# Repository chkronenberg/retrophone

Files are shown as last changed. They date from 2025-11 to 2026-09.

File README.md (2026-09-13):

# ☎️ Retro Rotary SIP Phone  
**Convert a classic rotary dial phone into a working SIP VoIP phone using a Raspberry Pi Zero 2 W, Debian Trixie, Baresip and Python 3**







If you enjoyed this project or found it helpful in setting up your own retro phone, you can buy me a coffee to help keep the bells ringing and the code flowing. ☕👇  


---

## 📚 Table of Contents

- [Overview](#-overview)
- [Features](#-features)
- [Hardware Setup](#-hardware-setup)
- [Software Installation](#️-software-installation)
- [Web Interface](#️-web-interface)
- [Log Files & Helper Tools](#-log-files--helper-tools)
- [WLAN & Network Stability](#-wlan--network-stability)
- [Troubleshooting (Audio & SIP)](#-audio-troubleshooting)
- [Credits & References](#-credits--references)

---

## 🧭 Overview
This open-source project demonstrates how to interface **classic telephony hardware** — rotary dial, hook switch, and mechanical bells — with **modern VoIP systems**.  
Built on **Raspberry Pi Zero 2 W** running **Debian Trixie**, **Baresip**, and **Python 3**.

- 📞 Incoming / outgoing VoIP calls via Baresip  
- 🔔 Authentic mechanical ringing driven by GPIO  
- ⚙️ Pulse-dial decoding and SIP dialing  
- 🧠 Flask-based web interface for SIP, logs & services  
- 🔊 Dial-tone playback and full audio through USB headset  

> 💬 **Need help or want to learn more about this project?**  
> You can ask questions, get setup guidance or troubleshooting tips directly via the  
> [**RetroPhone Custom GPT Assistant**](https://chatgpt.com/g/g-691247a8e5c0819190373fa77746ca60-retrophone).

---

## 🧩 Features

| Function | Description |
|---|---|
| ✅ Incoming calls | Mechanical bells ring; lifting handset answers |
| ✅ Outgoing calls | Rotary pulses decoded & sent to SIP |
| ✅ Dial tone | Analog-like dial tone playback |
| ✅ Web UI | Manage SIP, logs & restart services |
| ✅ GPIO monitoring | Check hook / dial / return contacts |
| ✅ Systemd services | Autostart & self-recovery |
| ✅ Persistent call history | Last 20 calls retained across reboots |
| ✅ Central JSON configuration | SIP, GPIO, audio, logging and timing settings |
| ✅ Backup from Web UI | Progress display and disaster-recovery archive |

---

## 🪛 Hardware Setup

This project uses an authentic rotary dial telephone combined with modern Raspberry Pi hardware.  
Below is the list of components used and verified to work with the current design.

### 🧩 Origin Story

The rotary phone used in this build wasn’t bought online — it was discovered in the **grandfather’s attic**, covered in dust but still mechanically perfect.  
After some careful cleaning and rewiring, the phone found a new life as a fully working SIP client.

### ⚙️ Required Components

| Component | Description | Link to buy
|---|---|---|
| ☎️ Old-style rotary telephone | The prototype uses a PTT **Modell 29**, found in the family attic. Any similar pulse-dial model will work. | 
| 🥧 Raspberry Pi Zero 2W | Compact, low-power computer controlling GPIO and running the SIP stack. Any variant of the Zero 2 W will do. | [digitec.ch](https://www.digitec.ch/de/s1/product/raspberry-pi-zero-2-w-entwicklungsboard-kit-47938039)
| 🥧 16GB SD-Card | Cheap option to save the data and run the OS of our Retrophone. | [digitec.ch](https://www.digitec.ch/de/s1/product/silicon-power-microsdhc-s-uhs-i-16-gb-microsdhc-u1-uhs-i-speicherkarte-13911929)
| 🔌 2x Dual D4184 MOSFET module | Used as high-current switches to drive the twin mechanical bell coils directly from the Pi GPIO pins. | [AliExpress](https://de.aliexpress.com/item/1005006478302624.html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)
| ⚡ 2 × 1N4007 diodes (1A / 1000V) | Wired in reverse across the bell coil outputs from the D4184 MOSFETs. These protect the switches from the voltage spike generated when the magnetic field in the coils collapses. **Ensure the band faces the positive line!** | [AliExpress](https://de.aliexpress.com/item/1005009923993443.html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)
| 🔋 Power supply 12V → 35V | Boost converter used to power the mechanical bell coils. | [AliExpress](https://de.aliexpress.com/item/1005007187154351.html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)
| 🔋 Power supply 12V → 5V | Step-down converter used to power the Raspberry Pi. | [AliExpress](https://de.aliexpress.com/item/1005006365697021.html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)
| 🔌 12 V DC power adapter | Common supply feeding both converters above. | [AliExpress](https://de.aliexpress.com/item/1005006865934857.html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)
| 🔌 Plug Jack Connector 5.5*2.1mm | DC plug connector and panel mount DC socket. | [AliExpress](https://de.aliexpress.com/item/1005003371403398.html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)
| 🧠 Raspberry Pi GPIO breakout board | For clean wiring and to mount all discrete components safely. | [AliExpress](https://de.aliexpress.com/item/1005008700849079.html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)
| 🎧 USB audio adapter or old USB Headset | Provides microphone and speaker ports for handset audio. | [AliExpress](https://de.aliexpress.com/item/1005003697317297.html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)
| 🎧 Speaker and microphone | Provides microphone and speaker ports for handset audio. | [Speaker - AliExpress](https://de.aliexpress.com/item/1005001740737952.html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), [Microphone - AliExpress](https://de.aliexpress.com/item/1005008016850118.html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)
| 🔗 Micro-USB “On-The-Go” (OTG) cable | Connects the USB audio interface to the Raspberry Pi Zero 2 W. | [AliExpress](https://de.aliexpress.com/item/32828564442.html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)

> The D4184 MOSFET module drives the two bell coils (RING_A and RING_B).  
> Each coil is protected by a 1N4007 diode, preventing reverse voltage damage when the magnetic field collapses.  
> A single 12 V power source feeds both the bell (via boost converter) and the Raspberry Pi (via step-down converter).

### 🖨️ 3D-Printed Holder
To securely mount all components inside the old telephone, a custom 3D-printed holder is used.
Required part:  
👉 [3D-Printed Component Holder](media/holder.stl)

The holder is designed to fit perfectly into the telephone housing and can be mounted using the original screw holes. All electronic components are fixed directly onto the holder, keeping everything clean, stable, and reversible without modifying the original phone.

---

### 📈 Architecture & Wiring Diagram

Below is the complete wiring layout for the Retro Rotary SIP Phone hardware setup.  
It shows the Raspberry Pi Zero 2 W GPIO connections, MOSFET bell driver, diodes, and power converters.

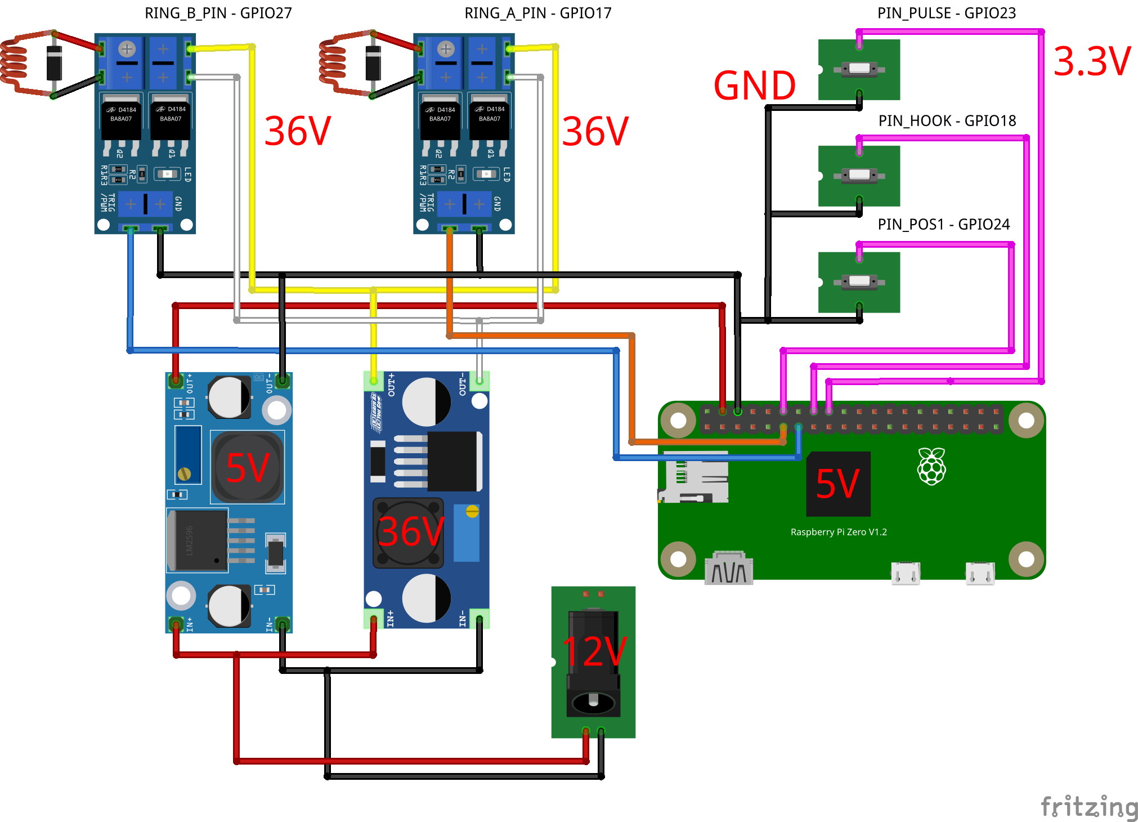
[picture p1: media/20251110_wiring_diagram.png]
Retro Rotary Phone Wiring Diagram


> **Tip:** Open the image in full size to see all GPIO labels and wiring colors clearly.  
> **Ensure you double-check the polarity of the 1N4007 diodes and the MOSFET inputs before powering on.**

```
+--------------------------------------------------------------+
|                     Retro Rotary SIP Phone                   |
|--------------------------------------------------------------|
|  Rotary Dial  |  Hook Switch  |  Bell Coils  |  USB Audio    |
|--------------------------------------------------------------|
|    GPIO 23    |    GPIO 18    |  GPIO 17/27  | Logitech H340 |
|               |               |              |    Headset    |
|--------------------------------------------------------------|
|  phone_daemon.py (Pulse/Hooks)  -> baresip (SIP stack)       |
|  ring_control.py (Bells)         -> GPIO Driver              |
|  webapp.py (Flask UI)            -> SIP + Logs + Control     |
+--------------------------------------------------------------+
```

---

### 🔩 GPIO Mapping Summary

| Signal | GPIO (BCM) | Description | Logic |
|---|---|---|---|
| HOOK | 18 | Handset switch | 0 = off-hook  1 = on-hook |
| PULSE | 23 | Rotary dial pulses | 1 = pulse active |
| POS1 | 24 | Dial return contact | 0 = dial turning |
| RING_A | 17 | Bell coil A | controlled by `ring_control.py` |
| RING_B | 27 | Bell coil B | controlled by `ring_control.py` |

> The original Swiss pulse-dial logic pulls to GND — no external pull-down resistors needed.
> All GPIO assignments can be changed later under **Settings** in the Web UI.

---

## ⚙️ Software Installation

### ⚙️ Automated Installation Script

To simplify setup, you can install and configure the entire RetroPhone environment with a single command using the `install_retrophone.sh` script.  
This script performs all required steps automatically:

- Installs system dependencies (Python, Flask, baresip, ALSA, etc.)  
- Creates required directories under `/usr/local/retrophone`, `/etc/retrophone`, and `/var/log/retrophone`  
- Copies all Python scripts and configuration files  
- Generates a default dial tone file  
- Sets correct permissions and sudo rules  
- Installs and enables the systemd services (`baresip`, `phone-daemon`, `retrophone-web`)  

**Run the following commands on your Raspberry Pi to use the script and install retrophone:**

```bash
cd /tmp
wget -O install_retrophone.sh https://raw.githubusercontent.com/chkronenberg/retrophone/main/install_retrophone.sh
chmod +x install_retrophone.sh
sudo ./install_retrophone.sh
```
>**🧠 Tip:**
>The script should be executed with **`sudo`** to ensure all directories, permissions, and services are created correctly.
>After completion, your Retro Rotary SIP Phone will be fully operational — including baresip registration, ringing, and web interface.

> **RetroPhone v2.0:** The automated installer is the recommended and authoritative installation method. The detailed steps below remain available as a reference for experienced users and custom installations.

### 1️⃣ Base System

Minimal Debian Trixie / Bookworm Lite.  
Enable SSH and network.

### 2️⃣ Dependencies

```bash
sudo apt-get update
sudo apt-get upgrade -y
sudo apt-get install -y python3 python3-flask python3-gpiozero python3-rpi.gpio \
  alsa-utils sox wget baresip
```

---

### 3️⃣ Create folders for **retrophone** and **baresip**

```bash
sudo mkdir -p /etc/retrophone/baresip
sudo mkdir -p /usr/local/retrophone
sudo mkdir -p /var/log/retrophone
sudo mkdir -p /run/retrophone
```

Run once to generate default config:

```bash
sudo -u pi baresip -f /etc/retrophone/baresip -e "quit"
```

### 4️⃣ Configure baresip

**Create the initial config-file for baresip**
Edit `/etc/retrophone/baresip/config`:

```bash
sudo tee /etc/retrophone/baresip/config >/dev/null <<'EOF'
#
# baresip configuration
#
#------------------------------------------------------------------------------

# Core
poll_method             epoll           # poll, select, epoll ..

# SIP
#sip_listen             0.0.0.0:5060
#sip_certificate        cert.pem
sip_cafile              /etc/ssl/certs/ca-certificates.crt
#sip_trans_def          udp
#sip_verify_server      yes

# Call
call_local_timeout      120
call_max_calls          4
call_hold_other_calls   yes

# Audio
#audio_path             /usr/share/baresip
audio_player            alsa,plughw:0,0
audio_source            alsa,plughw:0,0
audio_alert             alsa,null

#ausrc_srate            48000
#auplay_srate           48000
audio_srate             48000
#ausrc_channels         0
#auplay_channels        0
#audio_txmode           poll            # poll, thread
audio_level             no
ausrc_format            s16             # s16, float, ..
auplay_format           s16             # s16, float, ..
auenc_format            s16             # s16, float, ..
audec_format            s16             # s16, float, ..
audio_buffer            20-160          # ms

# AVT - Audio/Video Transport
rtp_tos                 184
#rtp_ports              10000-20000
#rtp_bandwidth          512-1024 # [kbit/s]
rtcp_mux                no
jitter_buffer_type      fixed           # off, fixed, adaptive
jitter_buffer_delay     5-10            # frames
#jitter_buffer_wish     6               # frames for start
rtp_stats               no

#------------------------------------------------------------------------------
# Modules

# UI Modules
module                  stdio.so
module                  httpd.so

# Audio driver Modules
module                  alsa.so

# Media NAT modules
module                  stun.so
module                  turn.so
module                  ice.so

#------------------------------------------------------------------------------
# Temporary Modules (loaded then unloaded)

module_tmp              uuid.so
module_tmp              account.so

#------------------------------------------------------------------------------
# Application Modules

module_app              auloop.so
module_app              contact.so
module_app              debug_cmd.so
module_app              menu.so
module_app              ctrl_tcp.so
module_app              vidloop.so

#------------------------------------------------------------------------------
# Module parameters

# UI Modules parameters
cons_listen             0.0.0.0:5555 # cons - Console UI UDP/TCP sockets

http_listen             127.0.0.1:8000 # httpd - HTTP Server

ctrl_tcp_listen         0.0.0.0:4444 # ctrl_tcp - TCP interface JSON

evdev_device            /dev/input/event0

# Opus codec parameters
opus_bitrate            28000 # 6000-510000

vumeter_stderr          yes

# Selfview
video_selfview          window # {window,pip}

# Menu
ring_aufile             none
EOF
```

**Create config file for the useraccount**
Edit `/etc/retrophone/baresip/accounts`:

```bash
sudo tee /etc/retrophone/baresip/accounts >/dev/null <<'EOF'
; YOUR ACCOUNT
<sip:phonenumber@sip.domain.url>;auth_user=USERNAME;auth_pass=YOUR_PASSWORD;outbound="sip:sip.domain.url;transport=udp";regint=300
EOF
```

---

### 5️⃣ Directory Structure

```bash
sudo mkdir -p /usr/local/retrophone /var/log/retrophone /run/retrophone
sudo mkdir -p /etc/retrophone
sudo chown -R pi:pi /usr/local/retrophone /var/log/retrophone /run/retrophone /etc/retrophone
sudo tee /etc/tmpfiles.d/retrophone.conf >/dev/null <<'EOF'
d /run/retrophone 0755 pi pi -
EOF
sudo systemd-tmpfiles --create /etc/tmpfiles.d/retrophone.conf
```

Copy all application files and install the shared configuration:

```bash
sudo cp files/gpio_monitor.py files/gpio_hook_monitor.py files/ring_control.py \
  files/phone_daemon.py files/webapp.py files/backup_retrophone.sh \
  files/persist_logs.sh files/favicon.ico /usr/local/retrophone/
sudo cp files/config.example.json /etc/retrophone/config.json
sudo chmod +x /usr/local/retrophone/*.py
sudo chmod +x /usr/local/retrophone/*.sh
sudo chown pi:pi /etc/retrophone/config.json
sudo chmod 640 /etc/retrophone/config.json
```

---

### 6️⃣ Create a Dial Tone

```bash
sox -n -r 8000 -c 1 /usr/local/retrophone/dialtone.wav synth 10 sin 425
```

---

### 7️⃣ Additional Permissions for "pi"

```bash
sudo visudo
```

Add:

```text
pi ALL=(ALL) NOPASSWD: /usr/bin/systemctl restart baresip.service
pi ALL=(ALL) NOPASSWD: /usr/bin/systemctl restart phone-daemon.service
pi ALL=(ALL) NOPASSWD: /usr/bin/systemctl restart retrophone-web.service
pi ALL=(root) NOPASSWD: /usr/local/retrophone/backup_retrophone.sh backup
```

**Permissions for the Web UI to change the SIP account**
```bash
sudo chown -R pi:pi /etc/retrophone/baresip
sudo chmod 640 /etc/retrophone/baresip/accounts
```

---

### 8️⃣ Systemd Services

#### 📞 `/etc/systemd/system/phone-daemon.service`

```bash
sudo tee /etc/systemd/system/phone-daemon.service >/dev/null <<'EOF'
[Unit]
Description=RetroPhone Dial/Hook Daemon
After=network.target sound.target baresip.service

[Service]
ExecStart=/usr/bin/python3 /usr/local/retrophone/phone_daemon.py
Restart=on-failure
User=pi
Group=pi
NoNewPrivileges=false

[Install]
WantedBy=multi-user.target
EOF

sudo systemctl daemon-reload
sudo systemctl enable --now phone-daemon.service

```

#### 🌐 `/etc/systemd/system/retrophone-web.service`
```bash
sudo tee /etc/systemd/system/retrophone-web.service >/dev/null <<'EOF'
[Unit]
Description=RetroPhone Web UI
After=network.target

[Service]
ExecStart=/usr/bin/python3 /usr/local/retrophone/webapp.py
WorkingDirectory=/usr/local/retrophone
User=pi
Group=pi
Environment=RETRO_WEB_USER=admin
Environment=RETRO_WEB_PASS=secret
Restart=on-failure
NoNewPrivileges=false

[Install]
WantedBy=multi-user.target
EOF

sudo systemctl daemon-reload
sudo systemctl enable --now retrophone-web.service

```

#### 📡 `/etc/systemd/system/baresip.service`
Edit `/etc/systemd/system/baresip.service`:

```bash
sudo tee /etc/systemd/system/baresip.service >/dev/null <<'EOF'
[Unit]
Description=baresip SIP client
After=network.target sound.target

[Service]
ExecStart=/usr/bin/baresip -f /etc/retrophone/baresip
Restart=on-failure
User=pi
NoNewPrivileges=false

[Install]
WantedBy=multi-user.target
EOF

sudo systemctl daemon-reload
sudo systemctl enable --now baresip.service

```

## 🖥️ Web Interface
Accessible at `http://<raspberrypi-ip>:8080`  

**Features**
- Configure the SIP account, GPIO pins, audio levels and expert timing values  
- Select the phone-daemon log level (`DEBUG`, `INFO`, `WARNING`, or `ERROR`)  
- View automatically refreshed phone, ring and baresip logs  
- View the persistent history of the last 20 calls, including missed calls  
- Create and monitor disaster-recovery backups  
- View temperature and WLAN status  
- Restart services and check their status (baresip / daemon / web)  

The shared configuration is stored in `/etc/retrophone/config.json`. Changes made in the Web UI are persistent; services that require the new values are restarted in a controlled manner.

Credentials are set via the `RETRO_WEB_USER` and `RETRO_WEB_PASS` environment variables in `retrophone-web.service`. The installer initially uses `admin` / `secret`; change these values before exposing the Web UI to an untrusted network.

<p align="center">
  <a href="media/webapp_login.png" target="_blank">
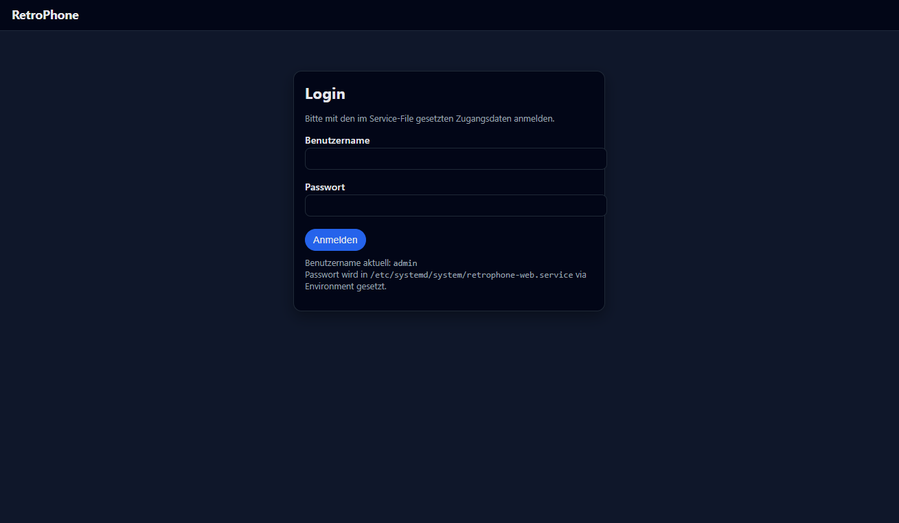
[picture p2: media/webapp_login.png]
Login View
    
  </a>
  <a href="media/webapp_dashboard_1.png" target="_blank">
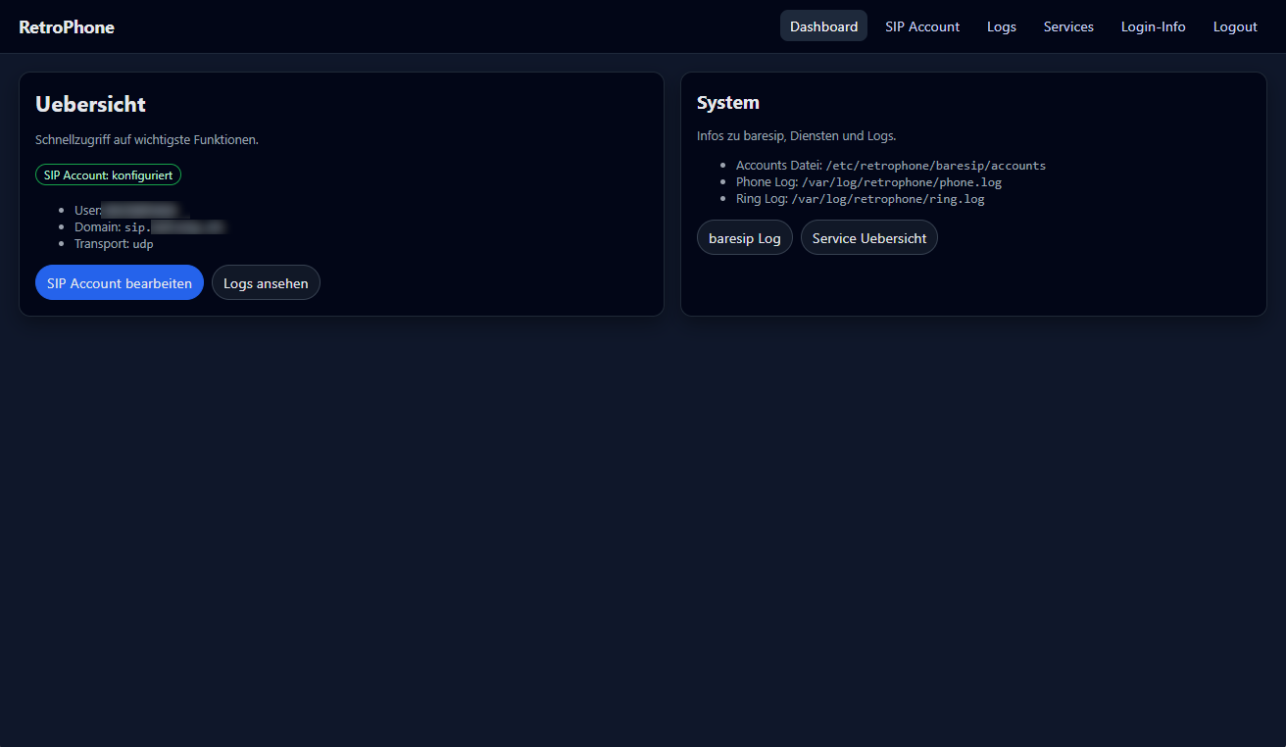
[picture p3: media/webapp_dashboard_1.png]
Dashboard View
    
  </a>
<a href="media/webapp_sip_account.png" target="_blank">
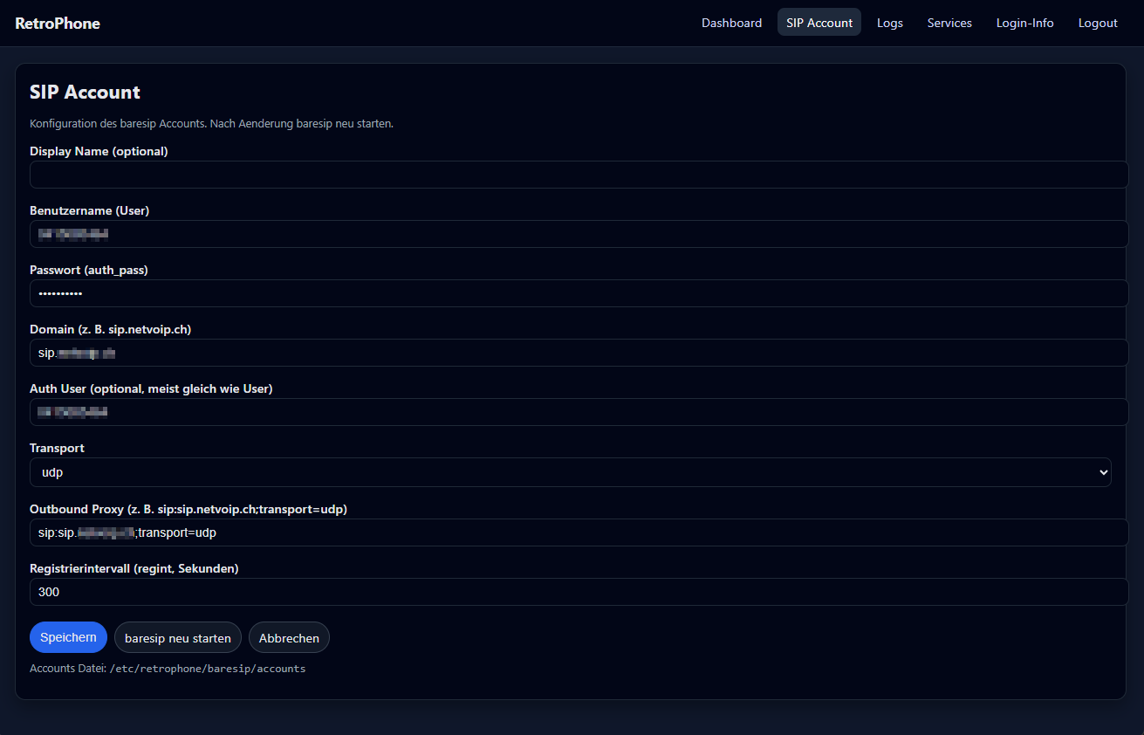
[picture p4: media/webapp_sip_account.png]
Dashboard SIP Account View
    
</a>
<a href="media/webapp_services.png" target="_blank">
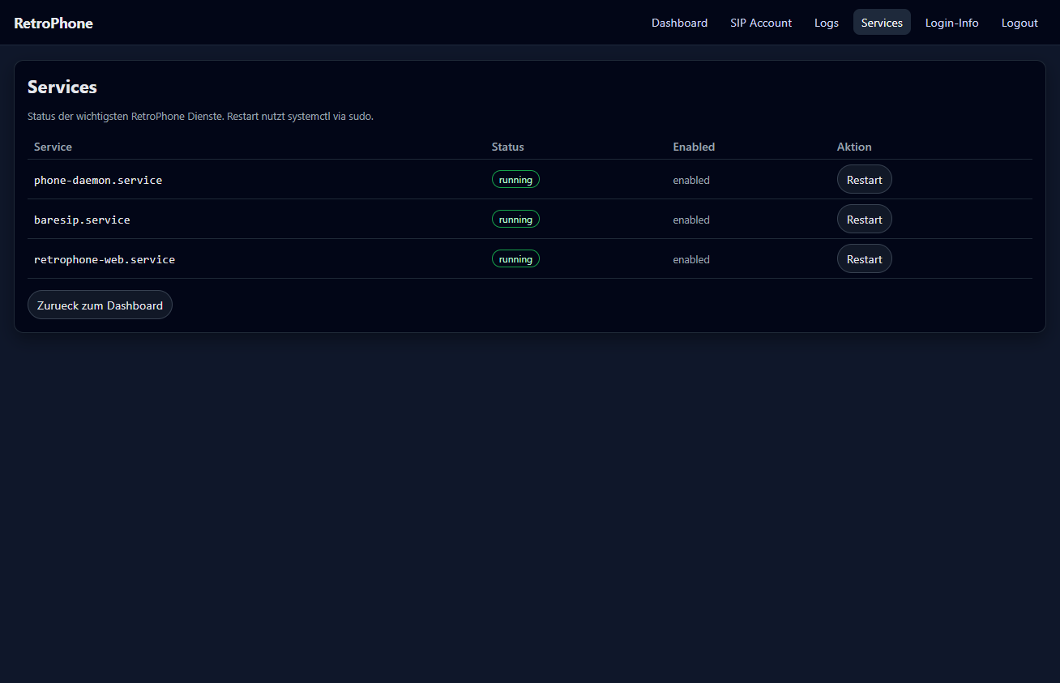
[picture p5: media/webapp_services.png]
Dashboard Services View
    
  </a>
</p>

<p align="center"><em>Click any image to view full size in a new tab.</em></p>

---

## 🧾 Log Files & Helper Tools

| Path | Description |
|---|---|
| `tail -f /run/retrophone/phone.log` | Main rotary daemon (dial, hook, call states) |
| `tail -f /run/retrophone/ring.log` | Bell control |
| `/var/log/retrophone/calls.jsonl` | Persistent call history restored after reboot |
| `journalctl -u baresip` | baresip SIP logs |

### 🆘 Helperscripts
| Script | Function |
|---|---|
| `gpio_monitor.py` | Show live GPIO states |
| `gpio_hook_monitor.py` | Hook only |
| `ring_control.py` | Manual ring test |

---

The technical phone and ring logs are intentionally stored below `/run/retrophone` and start fresh after a reboot. The call history is stored separately and persistently. Its location, along with all other paths, can be changed in `/etc/retrophone/config.json`.

---

## 📡 WLAN & Network Stability
The **Raspberry Pi Zero 2 W** uses the **Broadcom brcmfmac** Wi-Fi driver, which by default enables **power-saving**.  
During idle phases this can cause 🔻 lost SIP registrations, dropped Flask sessions, or temporary SSH timeouts.

The reference installation no longer uses NetworkManager. WLAN authentication is handled by **wpa_supplicant**, while addresses, routes and DNS are handled by **systemd-networkd** and **systemd-resolved**.

### 1️⃣ Replace NetworkManager with wpa_supplicant

> **Important:** Removing or stopping NetworkManager interrupts the current WLAN and SSH connection. Perform this migration from a local console or prepare all configuration files and enabled services before removing NetworkManager. Keep a backup of the previous network configuration.

Install the required components:

```bash
sudo apt-get update
sudo apt-get install -y wpasupplicant iw systemd-resolved
```

Generate the encrypted PSK with `wpa_passphrase`. The password is entered invisibly, is not stored in the shell history, and the clear-text comment normally produced by `wpa_passphrase` is removed:

```bash
read -rsp "WLAN password: " RETROPHONE_WIFI_PASSWORD; echo
wpa_passphrase "YOUR_SSID" "$RETROPHONE_WIFI_PASSWORD" \
  | sed '/^[[:space:]]*#psk=/d' \
  | sudo tee /etc/wpa_supplicant/wpa_supplicant.conf >/dev/null
unset RETROPHONE_WIFI_PASSWORD

sudo sed -i '1i ctrl_interface=DIR=/run/wpa_supplicant GROUP=netdev\nupdate_config=1\ncountry=CH\n' \
  /etc/wpa_supplicant/wpa_supplicant.conf
sudo sed -i '/^[[:space:]]*network={[[:space:]]*$/a\    scan_ssid=1' \
  /etc/wpa_supplicant/wpa_supplicant.conf
sudo chmod 600 /etc/wpa_supplicant/wpa_supplicant.conf
sudo ln -sfn /etc/wpa_supplicant/wpa_supplicant.conf \
  /etc/wpa_supplicant/wpa_supplicant-wlan0.conf
```

Replace `YOUR_SSID` with the actual WLAN name. The instance service `wpa_supplicant@wlan0` expects the interface-specific filename, so `wpa_supplicant-wlan0.conf` links to the central `wpa_supplicant.conf`. `scan_ssid=1` is required for the hidden WLAN used by the reference installation. Only the generated `network={...}` block is necessary when the Pi should not connect to any other WLAN.

Configure DHCP through `/etc/systemd/network/20-wlan0.network`:

```bash
sudo mkdir -p /etc/systemd/network
sudo tee /etc/systemd/network/20-wlan0.network >/dev/null <<'EOF'
[Match]
Name=wlan0

[Network]
DHCP=yes
EOF
```

Enable the replacement services before removing NetworkManager, then reboot:

```bash
sudo systemctl enable systemd-networkd.service
sudo systemctl enable systemd-resolved.service
sudo systemctl enable wpa_supplicant@wlan0.service
sudo ln -sf /run/systemd/resolve/stub-resolv.conf /etc/resolv.conf
sudo apt-get purge -y network-manager
sudo apt-get purge -y netplan.io cloud-init
sudo apt-get autoremove -y
sudo reboot
```

On the reference Raspberry Pi, APT also removed the dependent packages `rpi-usb-gadget`, `raspberrypi-net-mods`, and `rpi-cloud-init-mods`. Review APT's removal list before confirming because dependency packages can differ between Raspberry Pi OS releases and installations.

After reconnecting, verify the migration:

```bash
systemctl is-active systemd-networkd.service
systemctl is-active systemd-resolved.service
systemctl is-active wpa_supplicant@wlan0.service
networkctl status wlan0
```

All three services should report `active`, and `networkctl` should show `wlan0` as `routable`. The reference Pi currently receives its address by DHCP; a fixed address can instead be reserved for its MAC address on the router.

### 2️⃣ Temporarily disable Power Save
```bash
sudo iw dev wlan0 set power_save off
```

### 3️⃣ Disable Power Save permanently

Create a small systemd service so power saving is disabled after the WLAN interface is available:

```bash
sudo tee /etc/systemd/system/wlan-powersave-off.service >/dev/null <<'EOF'
[Unit]
Description=Disable WLAN power saving
After=sys-subsystem-net-devices-wlan0.device
Wants=sys-subsystem-net-devices-wlan0.device

[Service]
Type=oneshot
ExecStart=/usr/sbin/iw dev wlan0 set power_save off
RemainAfterExit=yes

[Install]
WantedBy=multi-user.target
EOF

sudo systemctl daemon-reload
sudo systemctl enable --now wlan-powersave-off.service
```

### 4️⃣ Alternative for older Raspberry Pi OS installations
Edit `/etc/rc.local` and add before `exit 0`:
```bash
iw dev wlan0 set power_save off
```

### 5️⃣ Optional driver tuning for brcmfmac

Only use these options if disabling power saving is not sufficient. Test them carefully because availability and behaviour depend on the installed kernel and firmware:

```bash
sudo rmmod brcmfmac
sudo modprobe brcmfmac roamoff=1 feature_disable=0x82000
```

### 6️⃣ Firmware update
```bash
sudo apt install --reinstall firmware-brcm80211 -y
```

### 7️⃣ Verify Power Save
```bash
iw dev wlan0 get power_save
# Expected → Power save: off
```

Disabling power saving resolved the observed idle disconnects on the reference installation. WLAN behaviour can still depend on the access point, driver and firmware, so verify the connection over an extended period.

---

## 🎧 Audio Troubleshooting

### 🔊 Audio Device Check

Before configuring Baresip or testing dial tones, check which audio devices are available on your Raspberry Pi.

Run the following commands:

```bash
aplay -l
arecord -l
```

This lists all playback and recording devices detected by ALSA.
**Example output:**

```text
**** List of PLAYBACK Hardware Devices ****
card 0: H340 [Logitech USB Headset H340], device 0: USB Audio [USB Audio]
  Subdevices: 1/1
  Subdevice #0: subdevice #0
card 1: vc4hdmi [vc4-hdmi], device 0: MAI PCM i2s-hifi-0 [MAI PCM i2s-hifi-0]
  Subdevices: 1/1
  Subdevice #0: subdevice #0
**** List of CAPTURE Hardware Devices ****
card 0: H340 [Logitech USB Headset H340], device 0: USB Audio [USB Audio]
  Subdevices: 1/1
  Subdevice #0: subdevice #0
```

In our case the playback hardware is the "Logitech USB Headset H340".
card 0, device 0 -> plughw:0,0
And the capture hardware as the following numbers:
card 0, device 0 -> plughw:0,0

If baresip reports `Unknown error -22`, check your ALSA config:

Edit `/etc/retrophone/baresip/config`

```ini
audio_player alsa,plughw:0,0
audio_source alsa,plughw:0,0
audio_alert alsa,null
audio_srate 48000
```
Playback test:
```bash
aplay -D plughw:0,0 /usr/local/retrophone/dialtone.wav
```

---

## 🧠 Credits & References
- Electronics and wiring inspired by [CrazyRobMiles / RaspberryPi-DialTelephone](https://github.com/CrazyRobMiles/RaspberryPi-DialTelephone)  
- VoIP engine [baresip](https://github.com/baresip/baresip)  
- Community resources: [baresip Discussions](https://github.com/baresip/baresip/discussions) · [r/raspberry_pi](https://reddit.com/r/raspberry_pi)

---

### 🪪 License
Released under the **MIT License**.  
Third-party components retain their original licenses.

---

### 🔎 Keywords for Discoverability
Retro rotary phone Raspberry Pi • Raspberry Pi Zero 2 W SIP phone • baresip python integration • GPIO pulse dialing • retro VoIP hardware project • mechanical bell driver • Flask web UI • Debian Trixie Raspberry Pi • DIY vintage telephone • embedded Linux telephony

---

### ⭐ Support & Collaboration
If you're a fan of vintage hardware and open-source telephony, give this project a star on GitHub or share your own build via a pull request or issue!
And if you enjoyed this project or found it helpful in setting up your own retro phone, you can buy me a coffee to help keep the bells ringing and the code flowing. ☕👇  



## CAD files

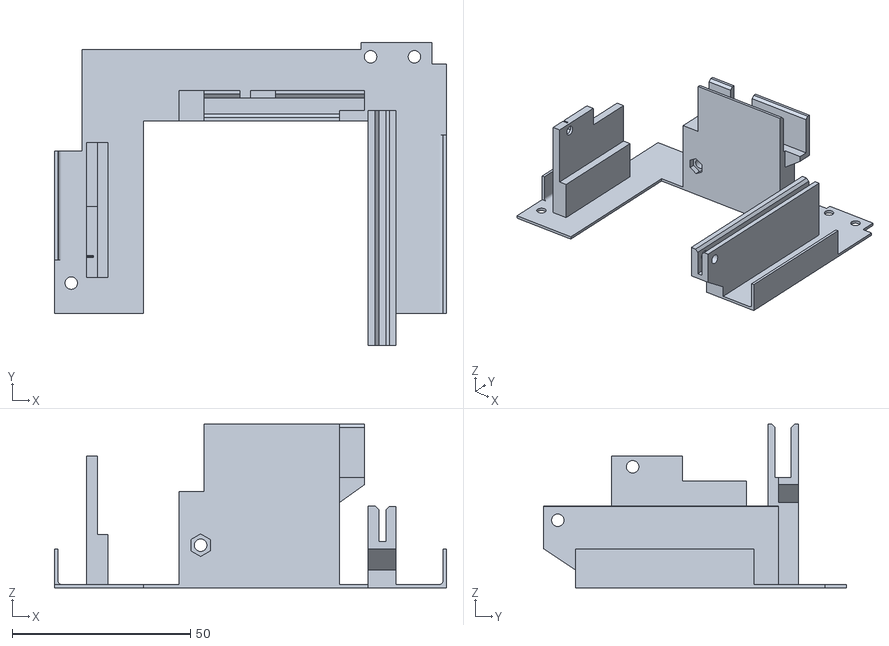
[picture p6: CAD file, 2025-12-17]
media/holder.stl
110.0 x 85.0 x 46.0

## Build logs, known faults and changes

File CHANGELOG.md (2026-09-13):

# Changelog

## v2.0 — 2026-09-13

### Highlights

- Completely redesigned responsive Web UI with live service, temperature and WLAN status
- Central `/etc/retrophone/config.json` for SIP, GPIO, audio, logging and expert settings
- Configurable phone-daemon log level (`DEBUG`, `INFO`, `WARNING`, `ERROR`)
- Persistent history of the last 20 calls
- Web-based ALSA handset and microphone volume controls
- Disaster-recovery backups with progress display
- Reduced repetitive phone-daemon and baresip log output
- Updated systemd-networkd and wpa_supplicant backup coverage
- New RetroPhone favicon

### Installation and migration

- Updated installer for the current `/etc/retrophone/baresip` layout
- Added a safe example configuration without SIP credentials
- Added runtime-directory creation and the required restricted sudo rules
- Existing installations retain their local `/etc/retrophone/config.json`

## v1.0

- Initial public RetroPhone release

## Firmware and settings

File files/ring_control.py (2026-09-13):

#!/usr/bin/env python3
import os, sys, time, signal, json, logging, logging.handlers

import RPi.GPIO as GPIO

CONFIG_PATH = os.environ.get("RETRO_CONFIG_PATH", "/etc/retrophone/config.json")
try:
    with open(CONFIG_PATH, "r", encoding="utf-8") as config_file:
        CONFIG = json.load(config_file)
    if not isinstance(CONFIG, dict):
        CONFIG = {}
except (FileNotFoundError, PermissionError, OSError, ValueError, TypeError):
    CONFIG = {}

GPIO_CONFIG = CONFIG.get("gpio", {}) if isinstance(CONFIG.get("gpio", {}), dict) else {}
RING_CONFIG = CONFIG.get("ring", {}) if isinstance(CONFIG.get("ring", {}), dict) else {}
PATH_CONFIG = CONFIG.get("paths", {}) if isinstance(CONFIG.get("paths", {}), dict) else {}

# === Pins ===
RING_A_PIN = int(GPIO_CONFIG.get("ring_a", 17))
RING_B_PIN = int(GPIO_CONFIG.get("ring_b", 27))

# Wenn du nur 1 Spule hast, auf True setzen
SINGLE_COIL = bool(RING_CONFIG.get("single_coil", False))

# Umschaltintervall der Spulen (Sekunden)
TOGGLE_INTERVAL = float(RING_CONFIG.get("toggle_interval", 0.02))

#LOG_DIR = "/var/log/retrophone"
LOG_DIR  = str(PATH_CONFIG.get("runtime_dir", "/run/retrophone"))
PID_DIR = LOG_DIR
PID_FILE = os.path.join(PID_DIR, "ring.pid")
LOG_PATH = os.path.join(LOG_DIR, "ring.log")

# === Logging ===
os.makedirs(LOG_DIR, exist_ok=True)
logger = logging.getLogger("ring")
logger.setLevel(logging.INFO)
handler = logging.handlers.TimedRotatingFileHandler(LOG_PATH, when="midnight", backupCount=7, encoding="utf-8")
handler.setFormatter(logging.Formatter("%(asctime)s %(levelname)s %(message)s"))
logger.addHandler(handler)

stop_flag = False

def sigterm_handler(signum, frame):
    global stop_flag
    stop_flag = True
    logger.info("Signal %s empfangen -> stop", signum)

def gpio_setup():
    GPIO.setmode(GPIO.BCM)
    GPIO.setup(RING_A_PIN, GPIO.OUT, initial=GPIO.LOW)
    GPIO.setup(RING_B_PIN, GPIO.OUT, initial=GPIO.LOW)

def gpio_all_low():
    try:
        GPIO.output(RING_A_PIN, GPIO.LOW)
        GPIO.output(RING_B_PIN, GPIO.LOW)
    except Exception:
        pass

def gpio_cleanup():
    try:
        gpio_all_low()
        GPIO.cleanup()
    except Exception:
        pass

def ensure_pid_dir():
    os.makedirs(PID_DIR, exist_ok=True)

def read_pid():
    try:
        with open(PID_FILE, "r") as f:
            return int(f.read().strip())
    except Exception:
        return None

def write_own_pid():
    ensure_pid_dir()
    with open(PID_FILE, "w") as f:
        f.write(str(os.getpid()))

def remove_pid():
    try:
        if os.path.exists(PID_FILE):
            os.remove(PID_FILE)
    except Exception:
        pass

def parse_cadence():
    cad = str(RING_CONFIG.get("cadence", os.environ.get("RINGCADENCE", "1000,3000")))
    try:
        on_ms, off_ms = [int(x.strip()) for x in cad.split(",")]
        on_ms = max(100, min(on_ms, 10000))
        off_ms = max(100, min(off_ms, 10000))
        return on_ms/1000.0, off_ms/1000.0
    except Exception:
        logger.warning("Ungültige RINGCADENCE '%s' -> 1000,3000", cad)
        return 1.0, 3.0

def ring_burst(duration_s):
    """Lässt für duration_s Sekunden klingeln."""
    end_t = time.time() + duration_s
    if SINGLE_COIL:
        # Eine Spule rhythmisch pulsen
        while not stop_flag and time.time() < end_t:
            GPIO.output(RING_A_PIN, GPIO.HIGH)
            time.sleep(TOGGLE_INTERVAL)
            GPIO.output(RING_A_PIN, GPIO.LOW)
            time.sleep(TOGGLE_INTERVAL)
    else:
        # Zwei Spulen alternierend
        state = False
        while not stop_flag and time.time() < end_t:
            state = not state
            GPIO.output(RING_A_PIN, GPIO.HIGH if state else GPIO.LOW)
            GPIO.output(RING_B_PIN, GPIO.LOW  if state else GPIO.HIGH)
            time.sleep(TOGGLE_INTERVAL)
        gpio_all_low()

def cmd_start():
    # Bereits laufend?
    old = read_pid()
    if old:
        try:
            os.kill(old, 0)
            logger.info("ring_control läuft bereits (PID %d)", old)
            # Safety: Pins auf Low
            gpio_setup(); gpio_all_low(); gpio_cleanup()
            return 0
        except Exception:
            # Stale PID
            remove_pid()

    # Im Vordergrund laufen, PID direkt vom echten Prozess schreiben
    signal.signal(signal.SIGTERM, sigterm_handler)
    signal.signal(signal.SIGINT,  sigterm_handler)

    write_own_pid()

    gpio_setup()
    gpio_all_low()

    on_s, off_s = parse_cadence()
    logger.info("Start ring loop (on=%.3fs off=%.3fs single=%s)", on_s, off_s, SINGLE_COIL)

    try:
        while not stop_flag:
            ring_burst(on_s)
            if stop_flag:
                break
            gpio_all_low()
            # Off-Phase abbrechbar schlafen
            slept = 0.0
            while not stop_flag and slept < off_s:
                time.sleep(0.05)
                slept += 0.05
    finally:
        logger.info("Stop ring loop, GPIO cleanup")
        gpio_cleanup()
        remove_pid()
    return 0

def cmd_stop():
    pid = read_pid()
    # Immer sofort pins low ziehen, egal was mit PID ist
    try:
        gpio_setup(); gpio_all_low(); gpio_cleanup()
    except Exception:
        pass

    if not pid:
        logger.info("ring_control nicht aktiv (kein PID)")
        return 0
    try:
        os.kill(pid, signal.SIGTERM)
        # Wartet bis zu 1.5 s
        for _ in range(30):
            try:
                os.kill(pid, 0)
                time.sleep(0.05)
            except OSError:
                break
        else:
            logger.warning("SIGTERM wirkungslos -> SIGKILL")
            os.kill(pid, signal.SIGKILL)
    except ProcessLookupError:
        pass
    except Exception as e:
        logger.warning("Stop-Fehler: %s", e)
    finally:
        remove_pid()
        # Sicherheit
        try:
            gpio_setup(); gpio_all_low(); gpio_cleanup()
        except Exception:
            pass
        logger.info("ring_control gestoppt")
    return 0

def cmd_status():
    pid = read_pid()
    if pid:
        try:
            os.kill(pid, 0)
            print("running")
            return 0
        except Exception:
            pass
    print("stopped")
    return 1

def cmd_oneshot(ms):
    gpio_setup()
    try:
        logger.info("Oneshot %d ms", ms)
        ring_burst(ms/1000.0)
        gpio_all_low()
    finally:
        gpio_cleanup()
    return 0

def main():
    if len(sys.argv) < 2:
        print("Usage: ring_control.py {start|stop|status|oneshot <ms>}", file=sys.stderr)
        sys.exit(2)
    cmd = sys.argv[1]
    if cmd == "start":
        sys.exit(cmd_start())
    elif cmd == "stop":
        sys.exit(cmd_stop())
    elif cmd == "status":
        sys.exit(cmd_status())
    elif cmd == "oneshot":
        if len(sys.argv) != 3:
            print("Usage: ring_control.py oneshot <ms>", file=sys.stderr)
            sys.exit(2)
        try:
            ms = int(sys.argv[2])
        except ValueError:
            print("Ungültige Zahl", file=sys.stderr)
            sys.exit(2)
        sys.exit(cmd_oneshot(ms))
    else:
        print("Usage: ring_control.py {start|stop|status|oneshot <ms>}", file=sys.stderr)
        sys.exit(2)

if __name__ == "__main__":
    main()

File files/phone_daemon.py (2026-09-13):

#!/usr/bin/env python3
import time, os, socket, json, logging, logging.handlers, subprocess
import RPi.GPIO as GPIO

CONFIG_PATH = os.environ.get("RETRO_CONFIG_PATH", "/etc/retrophone/config.json")

def load_config():
    try:
        with open(CONFIG_PATH, "r", encoding="utf-8") as config_file:
            data = json.load(config_file)
        return data if isinstance(data, dict) else {}
    except (FileNotFoundError, PermissionError, OSError, ValueError, TypeError):
        return {}

CONFIG = load_config()
GPIO_CONFIG = CONFIG.get("gpio", {}) if isinstance(CONFIG.get("gpio", {}), dict) else {}
PHONE_CONFIG = CONFIG.get("phone_daemon", {}) if isinstance(CONFIG.get("phone_daemon", {}), dict) else {}
BARESIP_CONFIG = CONFIG.get("baresip_control", {}) if isinstance(CONFIG.get("baresip_control", {}), dict) else {}
PATH_CONFIG = CONFIG.get("paths", {}) if isinstance(CONFIG.get("paths", {}), dict) else {}

# --- GPIO Definitionen ---
PIN_PULSE = int(GPIO_CONFIG.get("pulse", 23))
PIN_HOOK  = int(GPIO_CONFIG.get("hook", 18))
PIN_POS1  = int(GPIO_CONFIG.get("dial_position", 24))

# --- Zeiten und Parameter ---
DIAL_TIMEOUT      = float(PHONE_CONFIG.get("dial_timeout", 2.5))
DEBOUNCE          = float(PHONE_CONFIG.get("debounce", 0.006))
MIN_PULSE_LOW     = float(PHONE_CONFIG.get("min_pulse", 0.004))
MAX_PULSE_LOW     = float(PHONE_CONFIG.get("max_pulse", 0.08))

CALLS_POLL_SEC    = float(PHONE_CONFIG.get("calls_poll_interval", 0.6))
RING_WATCHDOG_SEC = float(PHONE_CONFIG.get("ring_watchdog", 2.0))

# --- baresip Steuerung (ctrl_tcp, JSON + Netstring) ---
BS_HOST            = str(BARESIP_CONFIG.get("host", "127.0.0.1"))
BS_PORT            = int(BARESIP_CONFIG.get("port", 4444))
BS_READ_TIMEOUT    = float(BARESIP_CONFIG.get("read_timeout", 0.8))
BS_CONNECT_TIMEOUT = float(BARESIP_CONFIG.get("connect_timeout", 1.0))
BS_RECONNECT_PAUSE = float(BARESIP_CONFIG.get("reconnect_pause", 0.8))

# --- Dialtone Datei ---
DIALTONE_WAV = str(PATH_CONFIG.get("dialtone", "/usr/local/retrophone/dialtone.wav"))

# --- Logging ---
VALID_LOG_LEVELS = {"DEBUG", "INFO", "WARNING", "ERROR"}

def configured_log_level():
    """Log-Level aus der gemeinsamen RetroPhone-Konfiguration lesen."""
    try:
        level = str(PHONE_CONFIG.get("log_level", "INFO")).upper()
        return level if level in VALID_LOG_LEVELS else "INFO"
    except (FileNotFoundError, PermissionError, OSError, ValueError, TypeError):
        return "INFO"

#LOG_DIR  = "/var/log/retrophone"
LOG_DIR  = str(PATH_CONFIG.get("runtime_dir", "/run/retrophone"))
LOG_PATH = os.path.join(LOG_DIR, "phone.log")
os.makedirs(LOG_DIR, exist_ok=True)

logger = logging.getLogger("retrophone")
LOG_LEVEL = configured_log_level()
logger.setLevel(getattr(logging, LOG_LEVEL))
handler = logging.handlers.TimedRotatingFileHandler(
    LOG_PATH, when="midnight", backupCount=7, encoding="utf-8"
)
handler.setFormatter(logging.Formatter("%(asctime)s %(levelname)s %(message)s"))
logger.addHandler(handler)
logger.propagate = False

# globaler Status fuer Dialtone und Call
dialtone_proc = None
call_in_progress = False


# ---------- GPIO ----------
def gpio_setup():
    GPIO.setmode(GPIO.BCM)
    for p in (PIN_PULSE, PIN_HOOK, PIN_POS1):
        GPIO.setup(p, GPIO.IN, pull_up_down=GPIO.PUD_UP)
    logger.info(
        "GPIO init: HOOK=%d PULSE=%d POS1=%d",
        PIN_HOOK, PIN_PULSE, PIN_POS1
    )

def offhook_from_raw(hook_raw: int) -> bool:
    # 0 = abgehoben, 1 = aufgelegt
    return hook_raw == 0


# ---------- baresip ctrl_tcp (JSON + Netstring) ----------
class BaresipCtrl:
    def __init__(self, host, port, read_timeout):
        self.host = host
        self.port = port
        self.read_timeout = read_timeout
        self.sock = None
        self.last_connect_fail = 0.0

    def _connect(self):
        now = time.time()
        if self.sock:
            return True
        if now - self.last_connect_fail < BS_RECONNECT_PAUSE:
            return False
        try:
            s = socket.create_connection(
                (self.host, self.port),
                timeout=BS_CONNECT_TIMEOUT
            )
            s.settimeout(self.read_timeout)
            self.sock = s
            logger.info("Mit baresip ctrl_tcp (JSON+Netstring) verbunden (%s:%d)", self.host, self.port)
            return True
        except Exception as e:
            self.last_connect_fail = now
            logger.error("baresip connect fehlgeschlagen: %s", e)
            self.sock = None
            return False

    def _send_netstring(self, payload: str):
        """
        Sende einen Netstring:
          <len>:<payload>,
        wobei payload ein JSON-String ist.
        """
        if not self.sock:
            return
        data = payload.encode("utf-8")
        header = f"{len(data)}:".encode("ascii")
        packet = header + data + b","
        self.sock.sendall(packet)

    def cmd(self, command: str, params: str = "", token: str = "retrophone") -> str:
        """
        Schickt ein JSON-Kommando wie:
          {"command":"dial","params":"078...","token":"retrophone"}
        verpackt als Netstring. Liefert die Rohantwort als String.
        """
        if not self._connect():
            return ""
        obj = {"command": command}
        if params:
            obj["params"] = params
        if token:
            obj["token"] = token
        try:
            payload = json.dumps(obj, separators=(",", ":"))
            self._send_netstring(payload)
            try:
                data = self.sock.recv(4096)
            except Exception:
                return ""
            resp = data.decode("utf-8", "ignore")
            logger.debug("baresip resp (%s): %s", command, resp.strip().replace("\n", " | "))
            return resp
        except Exception as e:
            logger.error("baresip cmd fehlgeschlagen (%s): %s", command, e)
            self.close()
            return ""

    def close(self):
        try:
            if self.sock:
                self.sock.close()
        except:
            pass
        self.sock = None

bs = BaresipCtrl(BS_HOST, BS_PORT, BS_READ_TIMEOUT)


# ---------- Telefonsteuerung ----------
def dial_number(num: str):
    global call_in_progress
    call_in_progress = True
    dialtone_stop()
    logger.info("Waehle via baresip (JSON): %s", num)
    bs.cmd("dial", num)

def hangup_all():
    global call_in_progress
    logger.info("Haenge auf (baresip JSON)")
    bs.cmd("hangup")
    call_in_progress = False
    dialtone_stop()

def answer_call():
    global call_in_progress
    logger.info("Nehme an (baresip JSON)")
    bs.cmd("accept")
    call_in_progress = True
    dialtone_stop()


# ---------- Klingelsteuerung (ueber ring_control.py) ----------
def ring_start():
    subprocess.Popen(
        ["/usr/local/retrophone/ring_control.py", "start"],
        close_fds=True
    )

def ring_stop():
    subprocess.call(
        ["/usr/local/retrophone/ring_control.py", "stop"]
    )
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

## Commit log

2025-11-10 add wiring diagram
2025-11-10 Add wiring diagram section to README
    Added wiring diagram and tips for hardware setup.
2025-12-17 STL-File for the 3d-printed component-holder inside
    [Elektronikhalter.stl]
2025-12-17 Add 3D-Printed Holder section to README
    Added section for 3D-Printed Holder with image reference.
2025-12-17 Revise 3D-Printed Holder section in README
    Updated the section on the 3D-Printed Holder for clarity and added a link to the STL file.
